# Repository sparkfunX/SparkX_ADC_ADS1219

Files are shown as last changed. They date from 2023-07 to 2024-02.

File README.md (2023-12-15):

SparkX Qwiic ADC ADS1219 - 24-Bit 4-Channel
========================================

SparkX Qwiic 24-Bit ADC - 4-Channel ADS1219

[*SparkX Qwiic 24-Bit ADC - 4-Channel ADS1219 (SPX-23455)*](https://www.sparkfun.com/products/23455)

Qwiic breakout board for the ADS1219 4-channel 24-bit ADC from TI.

A lot of the time you just need to add more analog inputs to solve a problem. It happens. The SparkX Qwiic 24-Bit ADC can provide four channels of I<sup>2</sup>C controlled ADC input to your Qwiic enabled project. These channels can be used as single-ended inputs, or in pairs for differential inputs, running at sample rates of up to 1kHz. What makes this ADC even more powerful is that it has a programmable x1 or x4 gain amplifier that lets you "zoom in" on a very small change in analog voltage (but will still effect your input range and resolution). Utilizing our handy Qwiic system, it is easy to connect it to the rest of your system. However, we have broken out 0.1"-spaced pads too in case you prefer to use a breadboard. The analog inputs and reference pins are all broken out on 0.1"-spaced pads too. This board does not have screw terminals - there was not enough room!

The ADS1219 can use its own internal 2.048V voltage reference for measurements, or you can provide your own reference via the REFP and REFN breakout pads. You can also provide your own VDDA (AVDD) by opening the jumper and connecting a voltage to the VDDA pad. This ADC board has eight address jumpers that let you choose one of sixteen unique addresses (0x40 to 0x4F). With these, you can connect up to sixteen of these on the same I<sup>2</sup>C bus and have 64 channels of ADC. The maximum resolution of the converter is 24-bits, corresponding to 244.14nV per count at a gain of x1. At a gain of x4, the resolution is 61.04nV per count. Note: the _effective_ resolution is limited to 20-bits.

Repository Contents
-------------------

* [**/Documents**](./Documents/) - TI datasheet
* [**/Hardware**](./Hardware/) - KiCad design files (_pcb, _sch), Schematic (PDF)
* [**/Hardware/Production**](./Hardware/Production/) - Production panel files (_pcb, gerbers)
* [**/Production_Test**](./Production_Test/) - The Arduino sketch we use to test the board

Documentation
--------------

* [**Arduino Library**](https://github.com/sparkfun/SparkFun_ADS1219_Arduino_Library) - Arduino library for the ADS1219.

License Information
-------------------

This product is _**open source**_! 

Please review the LICENSE.md file for license information. 

If you have any questions or concerns on licensing, please visit the [SparkFun Forum](https://forum.sparkfun.com/viewforum.php?f=152) and post a topic. For more specific questions about this board, please visit this section of the forum: [SparkFun Forums: SparkX](https://forum.sparkfun.com/viewforum.php?f=123)

Distributed as-is; no warranty is given.

- Your friends at SparkFun.

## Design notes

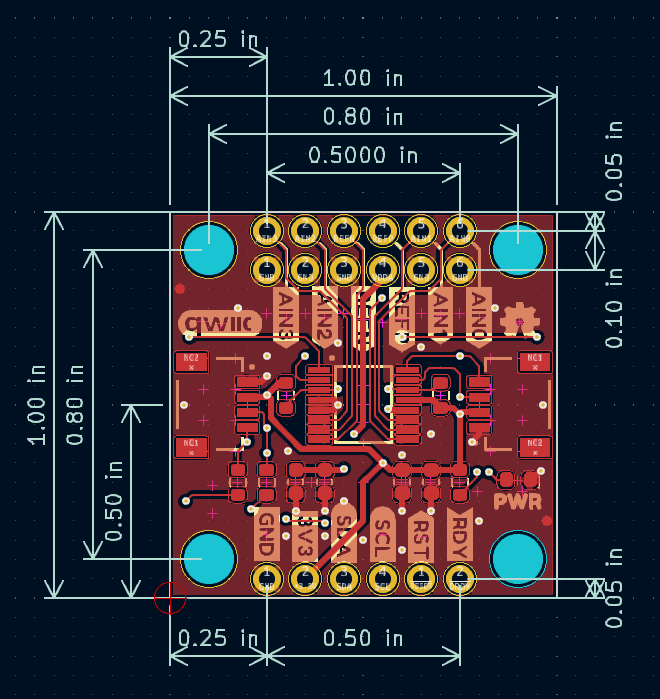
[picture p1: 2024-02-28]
Hardware/Dimensions.png

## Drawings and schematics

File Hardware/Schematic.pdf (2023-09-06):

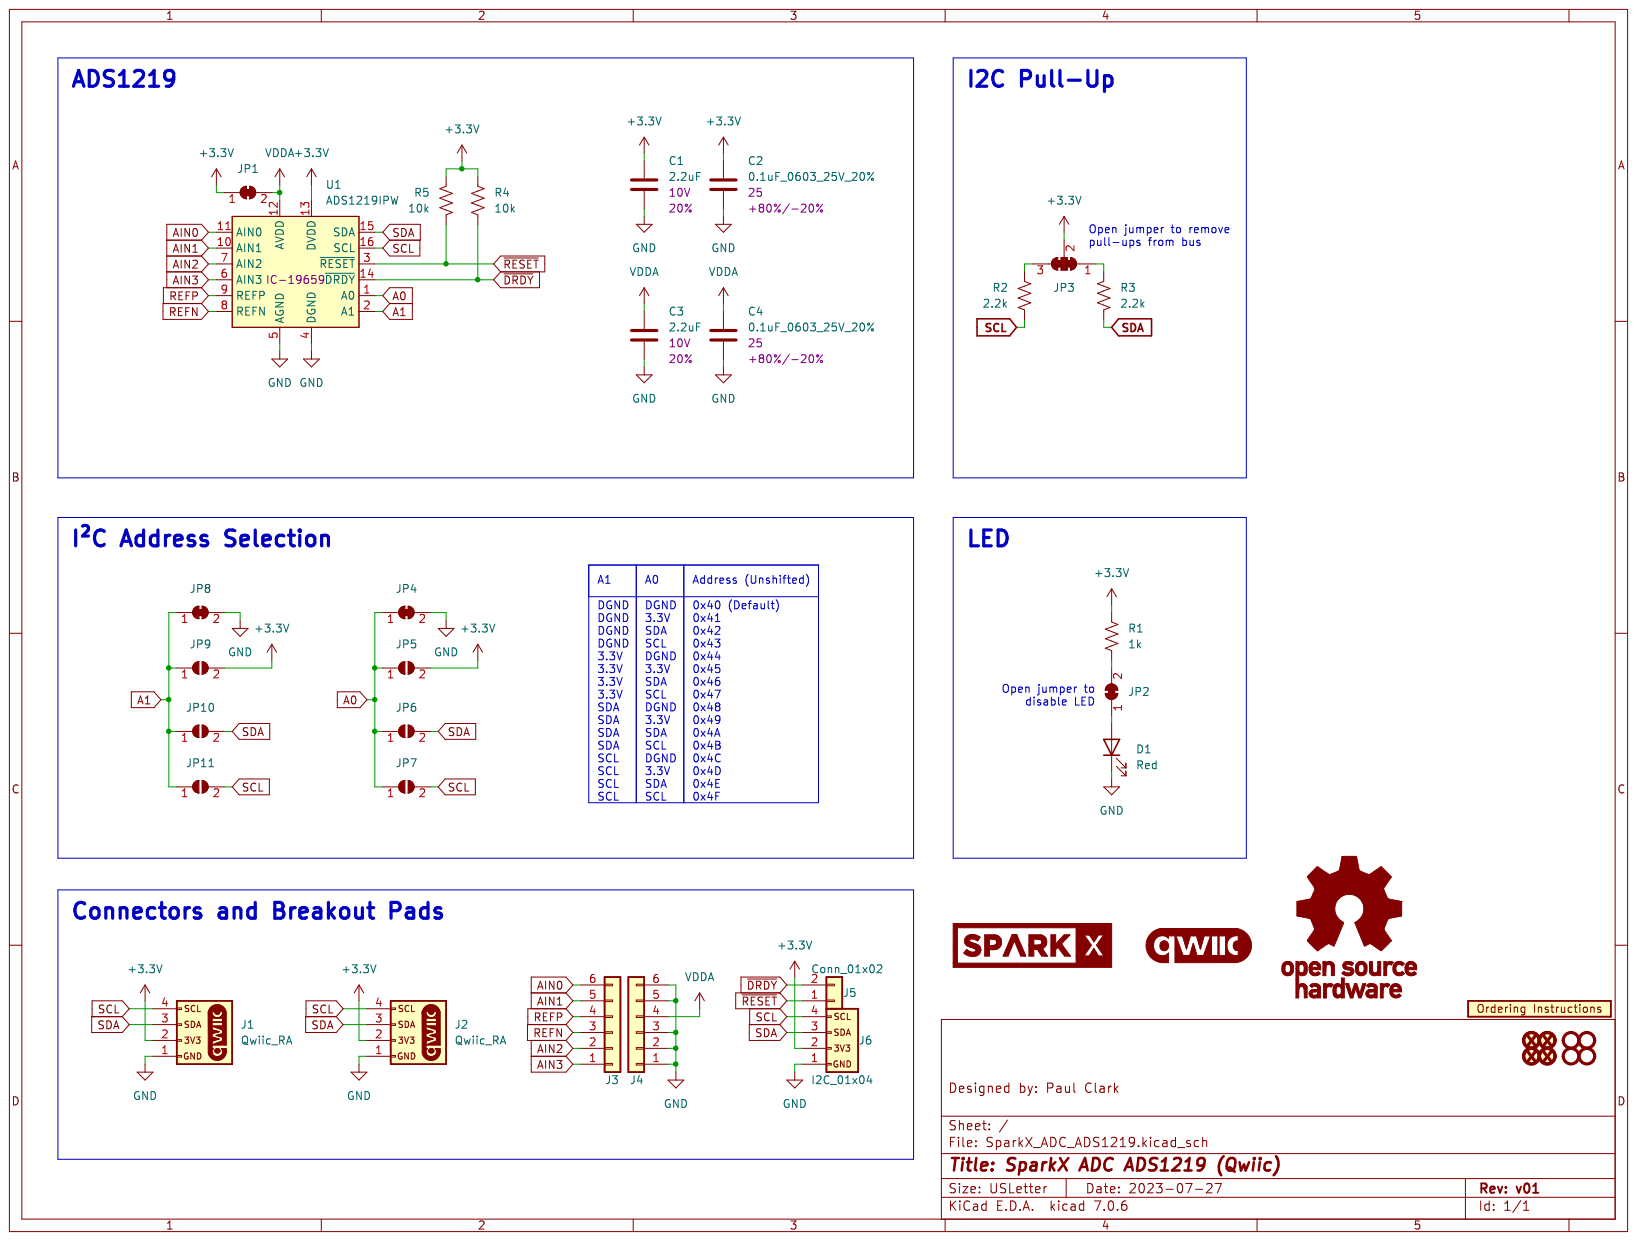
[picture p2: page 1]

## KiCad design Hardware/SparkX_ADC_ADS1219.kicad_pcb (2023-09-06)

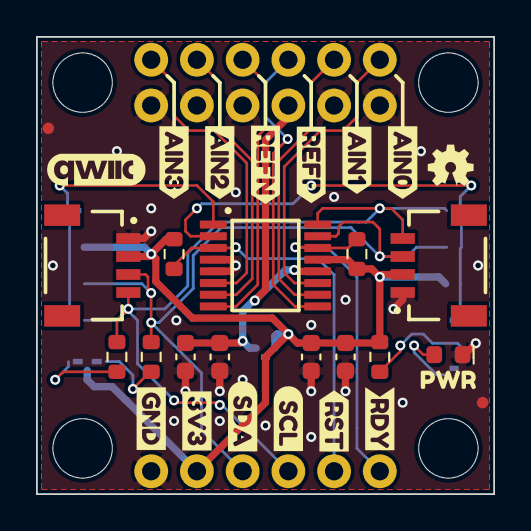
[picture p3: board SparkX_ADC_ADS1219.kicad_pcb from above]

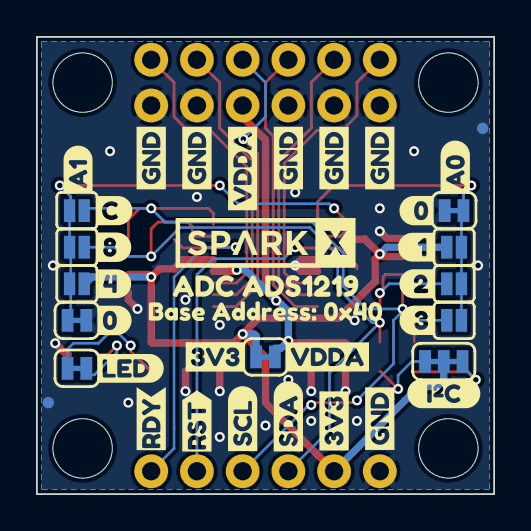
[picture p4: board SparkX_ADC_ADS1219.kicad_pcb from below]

Board: 2 copper layers, 25.4 x 25.4 mm, 79 parts (41 on the bottom side), 19 nets.

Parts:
C1, C3: 2.2uF; C_0603_1608Metric
C2, C4: 0.1uF_0603_25V_20%; C_0603_1608Metric
D1: Red; LED_0603_1608Metric
FID1, FID2, FID3, FID4: Fiducial_0.635; Fiducial_0.635mm
J1, J2: Qwiic_RA; JST04_1MM_RA
J3, J4: Conn_01x06; 1X06
J5: Conn_01x02; 1X02
J6: I2C_01x04; 1X04
JP1, JP2, JP4, JP8: SMT-JUMPER_2_NC_TRACE_SILK
JP3: SMT-JUMPER_3_2-NC_TRACE_SILK
JP5, JP6, JP7, JP9, JP10, JP11: SMT-JUMPER_2_NO_SILK
R1: 1k; R_0603_1608Metric
R2, R3: 2.2k; R_0603_1608Metric
R4, R5: 10k; R_0603_1608Metric
Ref**: Val**; OSHW-LOGO-MINI
ST1, ST2, ST3, ST4: Stand_off; STAND-OFF
U1: ADS1219IPW; TSSOP-16
U2: ORDERING_INSTRUCTIONS
kibuzzard-64C3B30F: G***; kibuzzard-64C3B30F
kibuzzard-64C3BD7A: G***; kibuzzard-64C3BD7A
kibuzzard-64C36D1A: G***; kibuzzard-64C36D1A
kibuzzard-64C36D2D: G***; kibuzzard-64C36D2D
kibuzzard-64C36D5B: G***; kibuzzard-64C36D5B
kibuzzard-64C36D6C: G***; kibuzzard-64C36D6C
kibuzzard-64C36D47: G***; kibuzzard-64C36D47
kibuzzard-64C36D91: G***; kibuzzard-64C36D91
kibuzzard-64C36E7A, kibuzzard-64C36E7A#2, kibuzzard-64C36E7A#3, kibuzzard-64C36E7A#4, kibuzzard-64C36E7A#5, kibuzzard-64C36E7A#6, kibuzzard-64C36E7A#7: G***; kibuzzard-64C36E7A
kibuzzard-64C36EF5: G***; kibuzzard-64C36EF5
kibuzzard-64C37A88, kibuzzard-64C37A88#2, kibuzzard-64C37A88#3: G***; kibuzzard-64C37A88
kibuzzard-64C37AD1: G***; kibuzzard-64C37AD1
kibuzzard-64C37B2E: G***; kibuzzard-64C37B2E
kibuzzard-64C37B4E: G***; kibuzzard-64C37B4E
kibuzzard-64C37B05: G***; kibuzzard-64C37B05
kibuzzard-64C37B97: G***; kibuzzard-64C37B97
kibuzzard-64C37BC1: G***; kibuzzard-64C37BC1
kibuzzard-64C37BF9: G***; kibuzzard-64C37BF9
kibuzzard-64C37C5C: G***; kibuzzard-64C37C5C
kibuzzard-64C37C16: G***; kibuzzard-64C37C16
kibuzzard-64C37CC9: G***; kibuzzard-64C37CC9
kibuzzard-64C37D63: G***; kibuzzard-64C37D63
kibuzzard-64C37FAB: G***; kibuzzard-64C37FAB
kibuzzard-64C375B4: G***; kibuzzard-64C375B4
kibuzzard-64C375BE: G***; kibuzzard-64C375BE
kibuzzard-64C375C5: G***; kibuzzard-64C375C5
kibuzzard-64C375DA: G***; kibuzzard-64C375DA
kibuzzard-64C375F2: G***; kibuzzard-64C375F2
kibuzzard-64C3756D: G***; kibuzzard-64C3756D
kibuzzard-64C3761E: G***; kibuzzard-64C3761E
kibuzzard-64C37519: G***; kibuzzard-64C37519
kibuzzard-64C37614: G***; kibuzzard-64C37614
kibuzzard-64C38090: G***; kibuzzard-64C38090

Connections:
+3.3V: C1.1, C2.1, J1.2, J2.2, J6.2, JP1.1 (A), JP3.2 (C), JP5.2 (B), JP9.2 (B), R1.1, R4.1, R5.1, U1.13 (DVDD)
A0: JP4.1 (A), JP5.1 (A), JP6.1 (A), JP7.1 (A), U1.1 (A0)
A1: JP8.1 (A), JP9.1 (A), JP10.1 (A), JP11.1 (A), U1.2 (A1)
AIN0: J3.6, U1.11 (AIN0)
AIN1: J3.5, U1.10 (AIN1)
AIN2: J3.2, U1.7 (AIN2)
AIN3: J3.1, U1.6 (AIN3)
GND: C1.2, C2.2, C3.2, C4.2, D1.1 (K), J1.1, J2.1, J4.1, J4.2, J4.3, J4.5, J4.6, J6.1, JP4.2 (B), JP8.2 (B), U1.4 (DGND), U1.5 (AGND)
unnamed: D1.2 (A), JP2.1 (A)
unnamed: JP2.2 (B), R1.2
unnamed: JP3.1 (A), R3.1
unnamed: JP3.3 (B), R2.1
REFN: J3.3, U1.8 (REFN)
REFP: J3.4, U1.9 (REFP)
SCL: J1.4, J2.4, J6.4, JP7.2 (B), JP11.2 (B), R2.2, U1.16 (SCL)
SDA: J1.3, J2.3, J6.3, JP6.2 (B), JP10.2 (B), R3.2, U1.15 (SDA)
VDDA: C3.1, C4.1, J4.4, JP1.2 (B), U1.12 (AVDD)
~DRDY: J5.2, R4.2, U1.14 (~DRDY)
~RESET: J5.1, R5.2, U1.3 (~RESET)

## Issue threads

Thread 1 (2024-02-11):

Correct 2's complement negative voltage bit mask

PaulZC, 2024-02-11:
As reported in [this customer comment](https://www.sparkfun.com/products/23455#comment-65c8149997cf6044780459b3), the bit mask for the 2's complement negative voltages is not correct.

PaulZC, 2024-02-11:
Correcting this [in the library](https://github.com/sparkfun/SparkFun_ADS1219_Arduino_Library/issues/2)

Closed 2024-02-11.

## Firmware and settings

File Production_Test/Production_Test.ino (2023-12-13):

/*
  Production test for the ADS1219 ADC.

  This is the code we use at SparkFun to test the Qwiic ADS1219.

  By: Paul Clark
  SparkFun Electronics
  Date: 2023/12/11
  SparkFun code, firmware, and software is released under the MIT License.
  Please see LICENSE.md for further details.

  Hardware Connections:
  IoT RedBoard --> ADS1219
  QWIIC        --> QWIIC

  Open the serial monitor at 115200 baud to see the test results.

  Feel like supporting our work? Buy a board from SparkFun!
  https://www.sparkfun.com/products/23455 - Qwiic ADS1219 1x1
*/

// You will need the SparkFun Toolkit. Click here to get it: http://librarymanager/All#SparkFun_Toolkit

#include <SparkFun_ADS1219.h> // Click here to get the library: http://librarymanager/All#SparkFun_ADS1219

SfeADS1219ArdI2C myADC;

void setup()
{
  pinMode(LED_BUILTIN, OUTPUT);
  digitalWrite(LED_BUILTIN, LOW);

  delay(1000); // Allow time for the microcontroller to start up

  Serial.begin(115200); // Begin the Serial console
  while (!Serial)
  {
    delay(100); // Wait for the user to open the Serial Monitor
  }
  Serial.println("SparkFun ADS1219 Production Test");
}

void loop()
{
  delay(250); // Try every 0.25 seconds

  Wire.begin();

  Wire.beginTransmission(0x40); // Detect ADS1219 on address 0x40
  if (Wire.endTransmission() != 0)
  {
    digitalWrite(LED_BUILTIN, LOW);
    Wire.end();
    Serial.println(F("Error: nothing detected on address 0x40"));
    return;
  }
  
  if (myADC.begin() == false) // Initialize ADC
  {
    digitalWrite(LED_BUILTIN, LOW);
    Wire.end();
    Serial.println(F("Error: .begin failed"));
    return;
  }

  myADC.setInputMultiplexer(ADS1219_CONFIG_MUX_SHORTED); // Read the voltage with AINP and AINN shorted to AVDD / 2

  for (int samples = 0; samples < 5; samples++) // Read the voltage 5 times to avoid any start-up noise
  {
    myADC.startSync(); // Start a single-shot conversion.

    int tries = 0;
    while ((myADC.dataReady() == false) && (tries < 25)) // Check if the conversion is complete.
    {
      delay(10); // The conversion is not complete. Wait a little to avoid pounding the I2C bus.
      tries++;
    }
  
    if (tries >= 25) // Check if we got data ready
    {
      digitalWrite(LED_BUILTIN, LOW);
      Wire.end();
      Serial.println(F("Error: no DRDY"));
      return;
    }

    if (!myADC.readConversion()) // Read the conversion result from the ADC. Store it internally.
    {
      digitalWrite(LED_BUILTIN, LOW);
      Wire.end();
      Serial.println(F("Error: readConversion failed"));
      return;
    }
  }

  int32_t sample = myADC.getConversionRaw(); // Get the raw ADC value. Note: this is NOT adjusted for gain.

  if (sample > 100)
  {
    digitalWrite(LED_BUILTIN, LOW);
    Wire.end();
    Serial.print(F("Error: ADC voltage too high: "));
    Serial.println(sample);
    return;
  }

  if (sample < -100)
  {
    digitalWrite(LED_BUILTIN, LOW);
    Wire.end();
    Serial.print(F("Error: ADC voltage too low: "));
    Serial.println(sample);
    return;
  }

  // All good!
  digitalWrite(LED_BUILTIN, HIGH);
  Wire.end();
  Serial.println(F("ADS1219 detected! Test passed! Check the PWR LED is on"));
}

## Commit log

2023-07-27 Very work-in-progress
    [Qwiic_ADS1219.kicad_pcb, Qwiic_ADS1219.kicad_sch]
2023-07-28 Rename everything
    [SparkX_ADC_ADS1219.kicad_pcb, SparkX_ADC_ADS1219.kicad_sch]
2023-09-06 Add panel
    [SparkX_ADC_ADS1219.kicad_pcb, SparkX_ADC_ADS1219.kicad_sch]
